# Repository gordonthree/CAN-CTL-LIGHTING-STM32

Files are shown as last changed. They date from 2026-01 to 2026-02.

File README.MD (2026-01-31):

# Interior Lighting Controller
Compact lighting controller module intended to interface with three-channel PWM dimmable lighting modules. This module works with other CAN-CTL modules using the robust CAN bus interface.

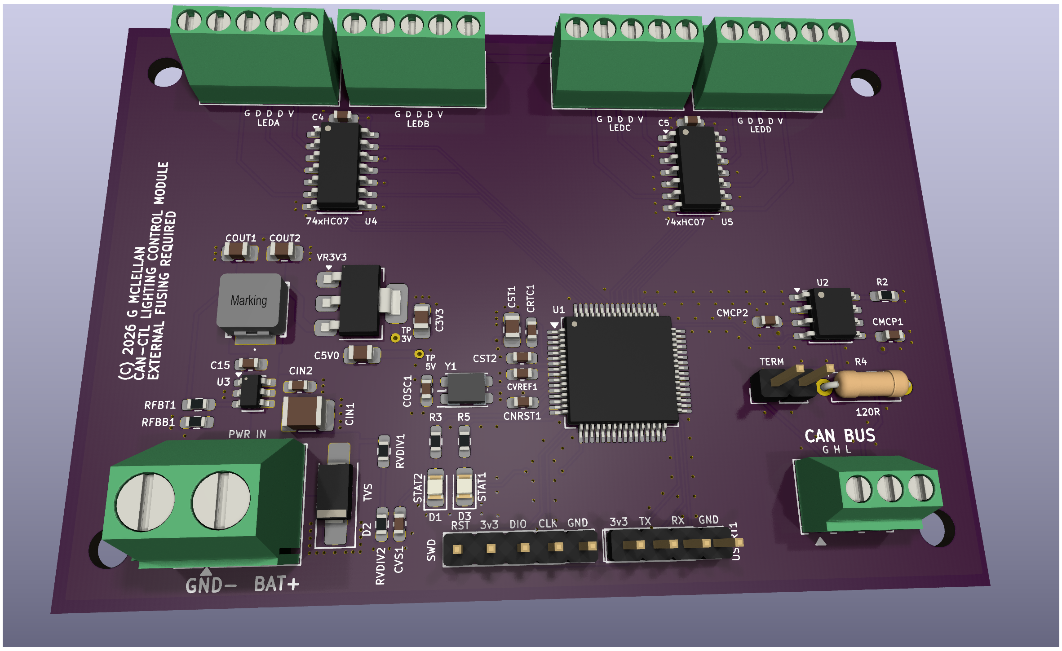
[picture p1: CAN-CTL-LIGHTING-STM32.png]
3d rendering of circuit board


* STM32G0B1RCT6 Microcontroller, 256k flash, 64mhz clock
* Automotive grade switch-mode power supply for 5v rail
* Automotive grade low-dropout linear supply for 3.3v rail
* 3-pin terminal block for CAN bus connection with drain
* Jumper selected CAN terminator resistor
* Four five position screw terminal connectors for 12v lighting modules
* 12 digital output channels in groups of 3, driven at 5v by hex schmitt line drivers
* Two LED indicators for status, controlled by the micro
* Bidirectional transient voltage protection diode for harsh environments
* Headers for USART1 serial port and SWD programming connector

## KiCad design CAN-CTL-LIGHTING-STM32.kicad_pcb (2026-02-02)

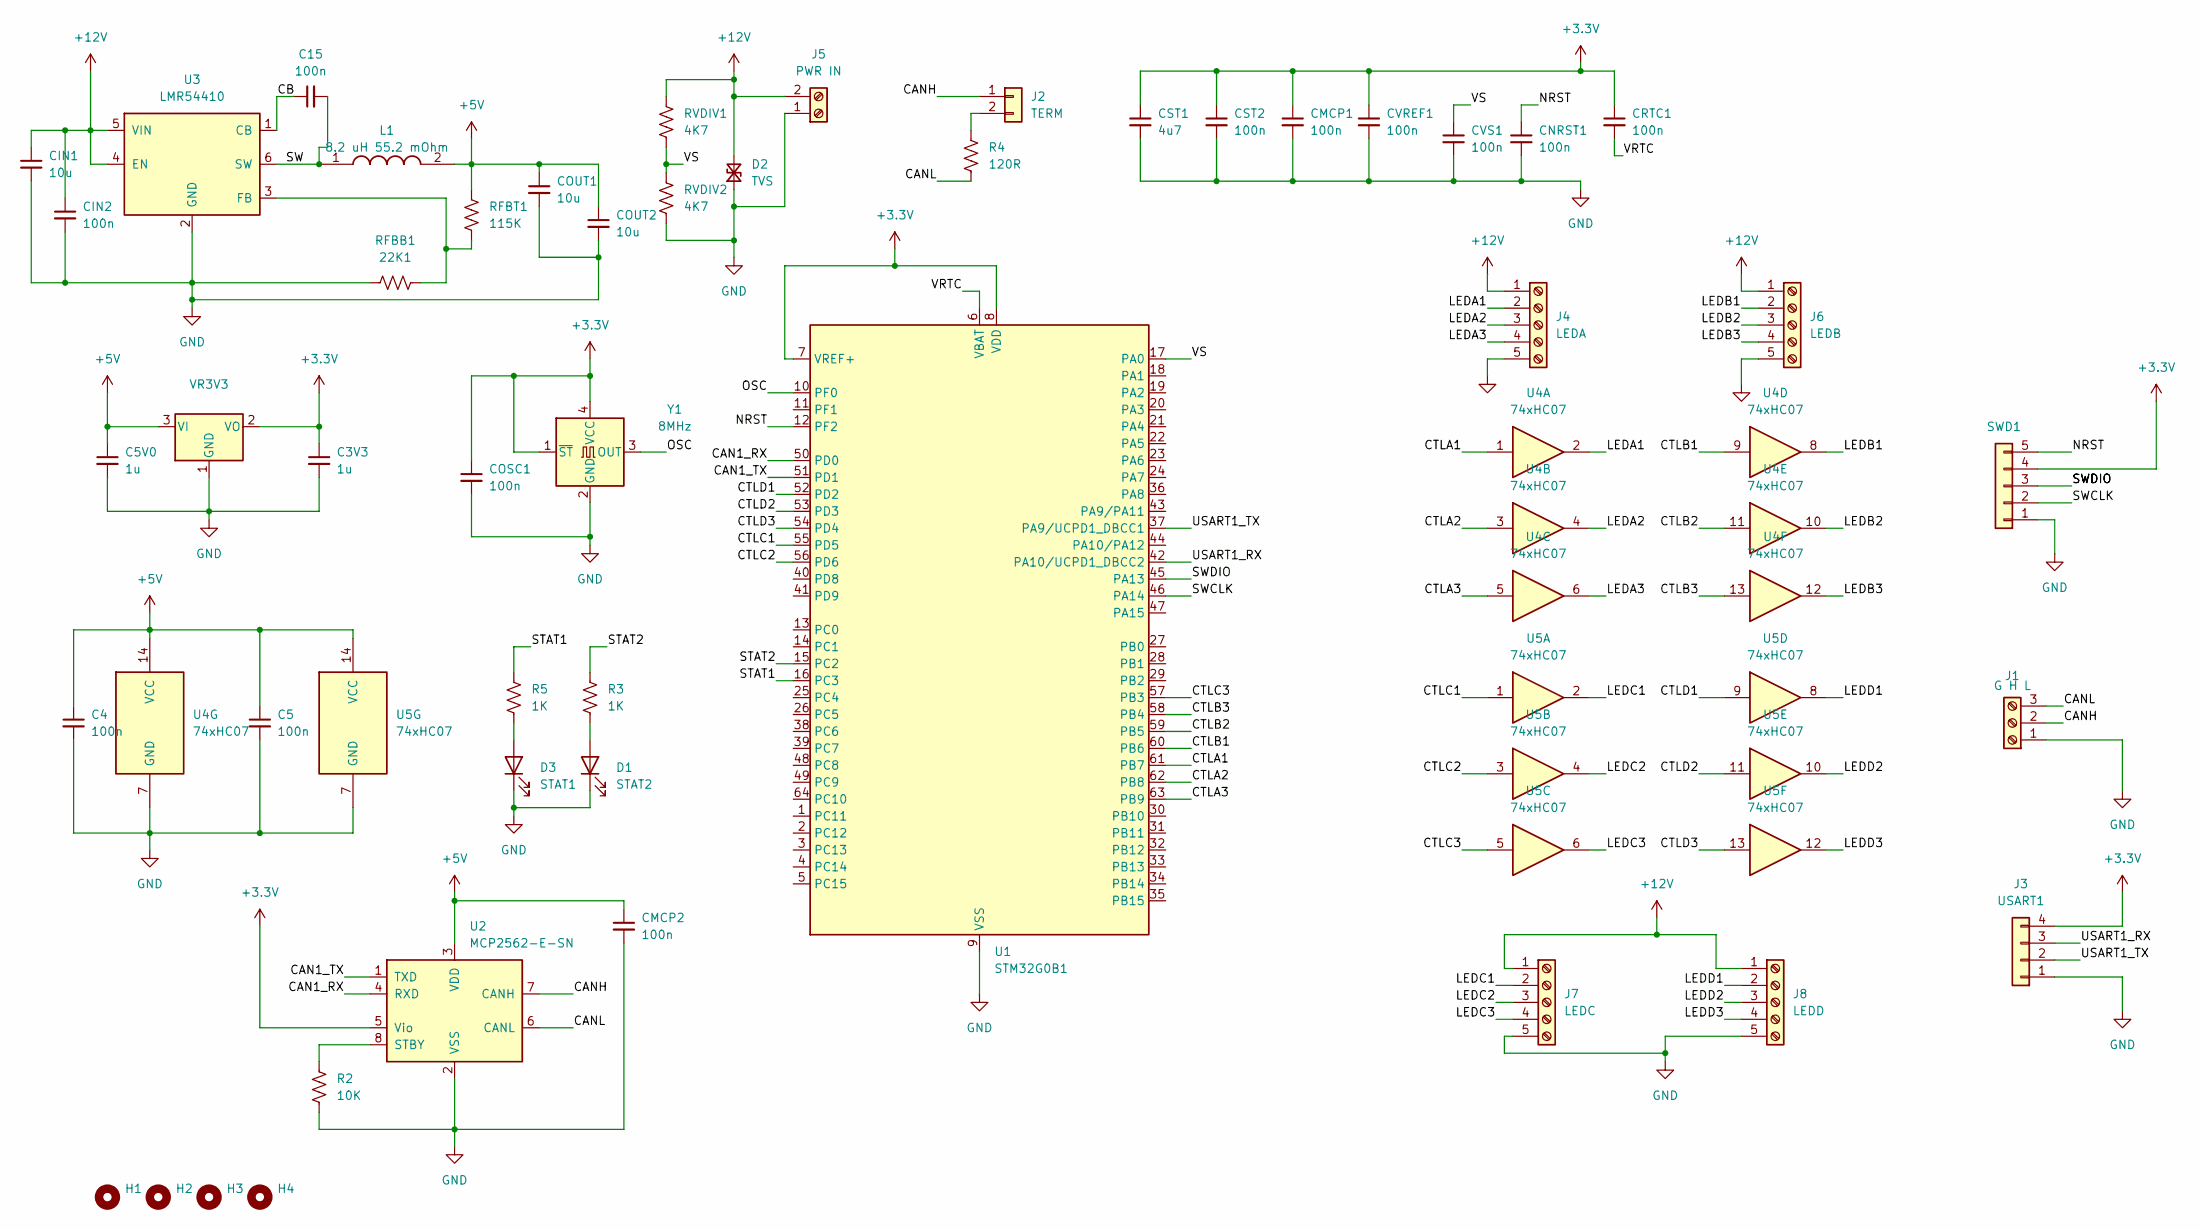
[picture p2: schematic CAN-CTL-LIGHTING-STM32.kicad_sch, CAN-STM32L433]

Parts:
C3V3, C5V0: 1u; C_0805_2012Metric_Pad1.18x1.45mm_HandSolder
C4, C5, C15: 100n; C_0603_1608Metric_Pad1.08x0.95mm_HandSolder
CIN1: 10u; C_1210_3225Metric_Pad1.33x2.70mm_HandSolder
CIN2: 100n; C_0603_1608Metric_Pad1.08x0.95mm_HandSolder
CMCP1, CMCP2: 100n; C_0603_1608Metric_Pad1.08x0.95mm_HandSolder
CNRST1: 100n; C_0603_1608Metric_Pad1.08x0.95mm_HandSolder
COSC1: 100n; C_0603_1608Metric_Pad1.08x0.95mm_HandSolder
COUT1, COUT2: 10u; C_0805_2012Metric_Pad1.18x1.45mm_HandSolder
CRTC1: 100n; C_0603_1608Metric_Pad1.08x0.95mm_HandSolder
CST1: 4u7; C_0805_2012Metric_Pad1.18x1.45mm_HandSolder
CST2: 100n; C_0603_1608Metric_Pad1.08x0.95mm_HandSolder
CVREF1: 100n; C_0603_1608Metric_Pad1.08x0.95mm_HandSolder
CVS1: 100n; C_0603_1608Metric_Pad1.08x0.95mm_HandSolder
D1: STAT2; LED_0805_2012Metric_Pad1.15x1.40mm_HandSolder
D2: TVS; D_SMA_Handsoldering
D3: STAT1; LED_0805_2012Metric_Pad1.15x1.40mm_HandSolder
H1, H2, H3, H4: MountingHole; MountingHole_3.2mm_M3_DIN965
J1: G H L; TerminalBlock_Phoenix_MPT-0,5-3-2.54_1x03_P2.54mm_Horizontal
J2: TERM; PinHeader_1x02_P2.54mm_Vertical
J3: USART1; PinHeader_1x04_P2.54mm_Vertical
J4: LEDA; TerminalBlock_Phoenix_MPT-0,5-5-2.54_1x05_P2.54mm_Horizontal
J5: PWR IN; TerminalBlock_Phoenix_MKDS-1,5-2_1x02_P5.00mm_Horizontal
J6: LEDB; TerminalBlock_Phoenix_MPT-0,5-5-2.54_1x05_P2.54mm_Horizontal
J7: LEDC; TerminalBlock_Phoenix_MPT-0,5-5-2.54_1x05_P2.54mm_Horizontal
J8: LEDD; TerminalBlock_Phoenix_MPT-0,5-5-2.54_1x05_P2.54mm_Horizontal
L1: 8.2 uH 55.2 mOhm; SRP5030HMT2R2M; Mouser Part Number SRP5030HMT-8R2M
R2: 10K; R_0603_1608Metric_Pad0.98x0.95mm_HandSolder
R3, R5: 1K; R_0603_1608Metric_Pad0.98x0.95mm_HandSolder
R4: 120R; R_Axial_DIN0207_L6.3mm_D2.5mm_P7.62mm_Horizontal
RFBB1: 22K1; R_0603_1608Metric_Pad0.98x0.95mm_HandSolder
RFBT1: 115K; R_0603_1608Metric_Pad0.98x0.95mm_HandSolder
RVDIV1, RVDIV2: 4K7; R_0603_1608Metric_Pad0.98x0.95mm_HandSolder
SWD1: SWD; PinHeader_1x05_P2.54mm_Vertical
U1: STM32G0B1; LQFP-64_10x10mm_P0.5mm; Manf Part STM32G0B1RCT6
U2: MCP2562-E-SN; SOIC-8_3.9x4.9mm_P1.27mm
U3: LMR54410; SOT-23-6
U4, U5: 74xHC07; SOIC-14_3.9x8.7mm_P1.27mm
VR3V3: TLV1117-33; SOT-223-3_TabPin2
Y1: 8MHz; Oscillator_SMD_EuroQuartz_XO32-4Pin_3.2x2.5mm_RotB_HandSold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

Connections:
+3.3V: C3V3.1, CMCP1.1, COSC1.1, CRTC1.1, CST1.1, CST2.1, CVREF1.1, J3.4, SWD1.4, U1.7 (VREF+), U1.8 (VDD), U2.5 (Vio), VR3V3.2 (VO), Y1.1 (~ST), Y1.4 (VCC)
+5V: C4.1, C5.1, C5V0.1, CMCP2.1, COUT1.1, COUT2.1, L1.2, RFBT1.1, U2.3 (VDD), U4.14 (VCC), U5.14 (VCC), VR3V3.3 (VI)
+12V: CIN1.1, CIN2.1, D2.2 (A2), J4.1, J5.2, J6.1, J7.1, J8.1, RVDIV1.1, U3.4 (EN), U3.5 (VIN)
/CAN1_RX: U1.50 (PD0), U2.4 (RXD)
/CAN1_TX: U1.51 (PD1), U2.1 (TXD)
/CANH: J1.2, J2.1, U2.7 (CANH)
/CANL: J1.3, R4.2, U2.6 (CANL)
/CB: C15.1, U3.1 (CB)
/CTLA1: U1.61 (PB7), U4.1
/CTLA2: U1.62 (PB8), U4.3
/CTLA3: U1.63 (PB9), U4.5
/CTLB1: U1.60 (PB6), U4.9
/CTLB2: U1.59 (PB5), U4.11
/CTLB3: U1.58 (PB4), U4.13
/CTLC1: U1.55 (PD5), U5.1
/CTLC2: U1.56 (PD6), U5.3
/CTLC3: U1.57 (PB3), U5.5
/CTLD1: U1.52 (PD2), U5.9
/CTLD2: U1.53 (PD3), U5.11
/CTLD3: U1.54 (PD4), U5.13
/LEDA1: J4.2, U4.2
/LEDA2: J4.3, U4.4
/LEDA3: J4.4, U4.6
/LEDB1: J6.2, U4.8
/LEDB2: J6.3, U4.10
/LEDB3: J6.4, U4.12
/LEDC1: J7.2, U5.2
/LEDC2: J7.3, U5.4
/LEDC3: J7.4, U5.6
/LEDD1: J8.2, U5.8
/LEDD2: J8.3, U5.10
/LEDD3: J8.4, U5.12
/NRST: CNRST1.1, SWD1.5, U1.12 (PF2)
/OSC: U1.10 (PF0), Y1.3 (OUT)
/STAT1: R5.2, U1.16 (PC3)
/STAT2: R3.2, U1.15 (PC2)
/SW: C15.2, L1.1, U3.6 (SW)
/SWCLK: SWD1.2, U1.46 (PA14)
/SWDIO: SWD1.3, U1.45 (PA13)
/USART1_RX: J3.3, U1.42 (PA10/UCPD1_DBCC2)
/USART1_TX: J3.2, U1.37 (PA9/UCPD1_DBCC1)
/VRTC: CRTC1.2, U1.6 (VBAT)
/VS: CVS1.1, RVDIV1.2, RVDIV2.1, U1.17 (PA0)
GND: C3V3.2, C4.2, C5.2, C5V0.2, CIN1.2, CIN2.2, CMCP1.2, CMCP2.2, CNRST1.2, COSC1.2, COUT1.2, COUT2.2, CST1.2, CST2.2, CVREF1.2, CVS1.2, D1.1 (K), D2.1 (A1), D3.1 (K), J1.1, J3.1, J4.5, J5.1, J6.5, J7.5, J8.5, R2.2, RFBB1.1, RVDIV2.2, SWD1.1, U1.9 (VSS), U2.2 (VSS), U3.2 (GND), U4.7 (GND), U5.7 (GND), VR3V3.1 (GND), Y1.2 (GND)
unnamed: D1.2 (A), R3.1
unnamed: D3.2 (A), R5.1
unnamed: J2.2, R4.1
unnamed: R2.1, U2.8 (STBY)
unnamed: RFBB1.2, RFBT1.2, U3.3 (FB)

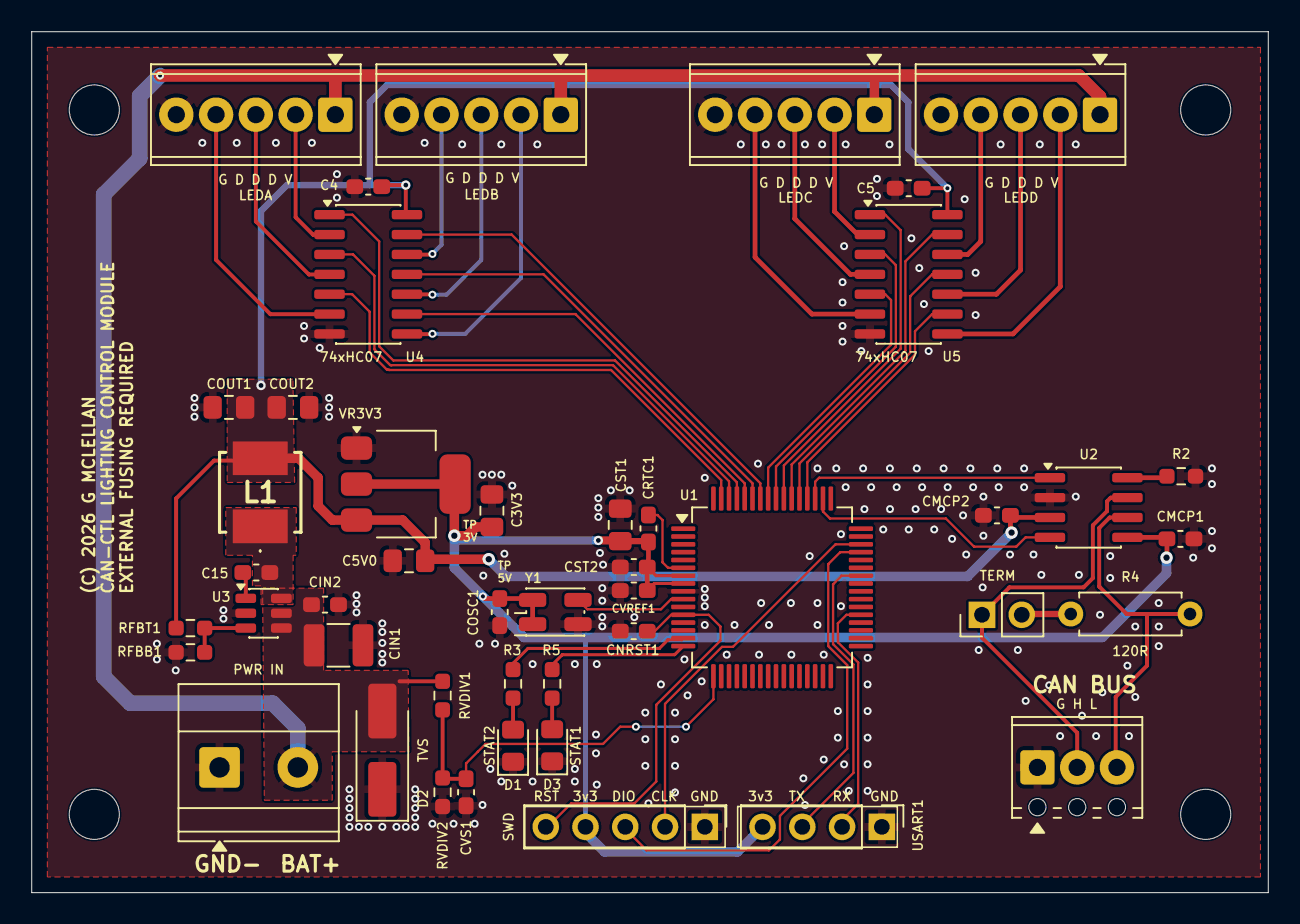
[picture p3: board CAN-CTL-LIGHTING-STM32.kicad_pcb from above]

Board: 2 copper layers, 79.0 x 55.0 mm, 50 parts (0 on the bottom side), 49 nets.

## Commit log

2026-01-25 drc passed
    [CAN-CTL-LIGHTING-STM32.kicad_pcb]
2026-01-25 silkscreen updates, swapped ground and H on can connector
    [CAN-CTL-LIGHTING-STM32.kicad_pcb, CAN-CTL-LIGHTING-STM32.kicad_sch]
2026-01-31 added copyright text
    [CAN-CTL-LIGHTING-STM32.kicad_pcb]
2026-02-02 added crystal osc
    [CAN-CTL-LIGHTING-STM32.kicad_pcb, CAN-CTL-LIGHTING-STM32.kicad_sch]

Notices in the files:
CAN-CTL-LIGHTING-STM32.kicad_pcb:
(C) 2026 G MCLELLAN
